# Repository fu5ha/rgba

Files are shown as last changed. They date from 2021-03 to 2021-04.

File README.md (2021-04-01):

# `rgba` - reasonably good bluetooth audio

The `rgba` is a tiny (41x20mm PCB), extremely high fidelity Bluetooth audio receiver meant to attach inline to the cord of
a pair of IEMs. It aims to provide as high quality audio as possible while retaining reasonable battery life and
its small form factor. It is designed to pair well with high sensitivity, low impedance IEMs. For use with
lower sensitivity, harder to drive headphones (or IEMs), you'll need to adjust the values of the resistor feedback network
around the Op Amp to provide the proper output power. See [this document](https://www.ti.com/lit/ug/tiduaw1/tiduaw1.pdf),
especially sections 1 through 3, for more information. Reach out to me via GitHub issue or social media (listed on my
GitHub profile) and I'd be happy to guide you on this.

## Schematic

See [rgba.pdf](/rgba.pdf) for a PDF copy of the schematic, or open the repo's root as a project in KiCad and launch Eeschema.

## Renders

Here are a couple of renders of the latest version of the PCB.

front side
back side

## Bill of Materials

A bill of materials is available in HTML format, with links to sourcing information and
interactive PCB board view useful when performing assembly. View it here: <https://termhn.github.io/rgba/ibom.html>

Not included in the BOM is a battery. You can use any single cell LiPo (3.7V) LiPo battery up to
500mAh in capacity. You'll likely need to either re-terminate the batteries with the proper connector
(2-pin JST-ACH [plug housing](https://www.digikey.com/en/products/detail/jst-sales-america-inc/ACHR-02V-S/1647783c)
and [crimp leads](https://www.digikey.com/en/products/detail/jst-sales-america-inc/ASACHSACH28W51/6009445)
can be found on DigiKey) or lop off the included connector and solder the leads directly to the board.

## PCB Sourcing

I recommend ordering PCBs through OSH Park because their 4 layer process has the needed precision at a reasonable price
(JLCPCB for example will cost you a lot more to get the needed 0.2/0.4 diameter vias), is good quality, and are a cool
organization to support. Plus their PCBs are a super purdy purple :d

You can order some of the rev 1.1 PCBs directly using this link: -link will be inserted here when it has been tested working-

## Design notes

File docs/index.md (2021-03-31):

# `rgba` - reasonably good bluetooth audio

The `rgba` is a tiny (41x20mm PCB), extremely high fidelity Bluetooth audio receiver meant to attach inline to the cord of
a pair of IEMs. It aims to provide as high quality audio as possible while retaining reasonable battery life and
its small form factor. For more information, see the [project README](https://github.com/termhn/rgba).

## Interactive Bill of Materials

[View the interactive BOM](ibom.html)

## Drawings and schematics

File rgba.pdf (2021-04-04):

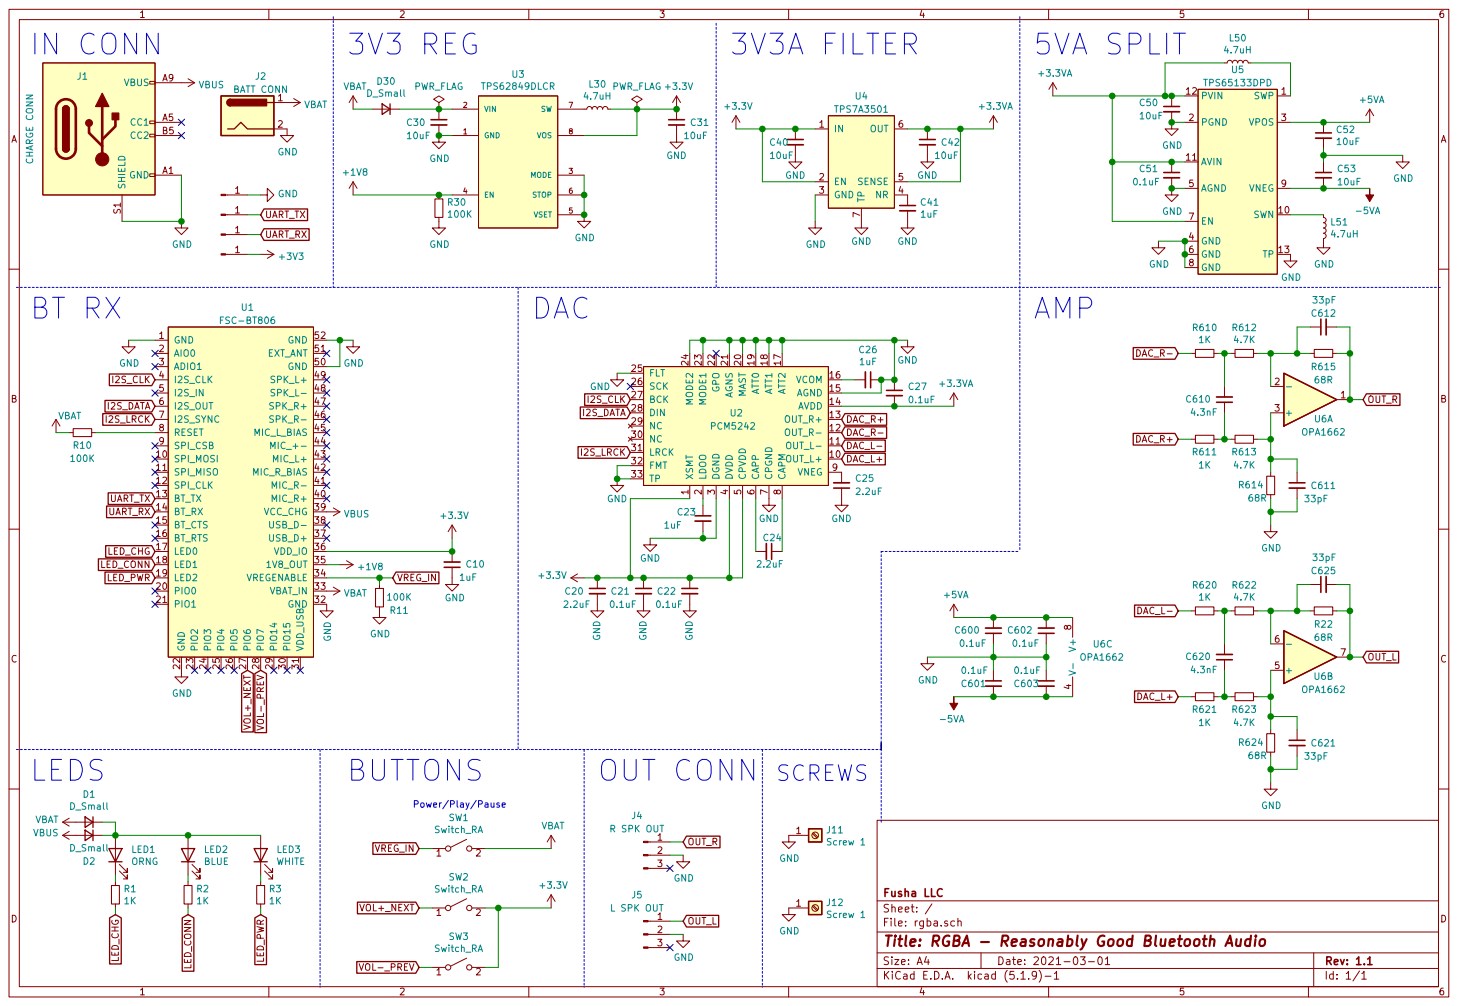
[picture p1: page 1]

2 MAST 20 AGNS 21 GPO 22 MODE1 23 MODE2 24 FLT 25 SCK 26 BCK 27 DIN 28 NC 29 DGND

1 OUT_L+ 10 OUT_L- 11 OUT_R- 12 OUT_R+ 13 AVDD 14 AGND 15 VCOM 16 ATT2 17 ATT1 18 ATT0 19 LDOO

File: rgba.sch Sheet: / Fusha LLC

Id: 1/1 Title: RGBA - Reasonably Good Bluetooth Audio

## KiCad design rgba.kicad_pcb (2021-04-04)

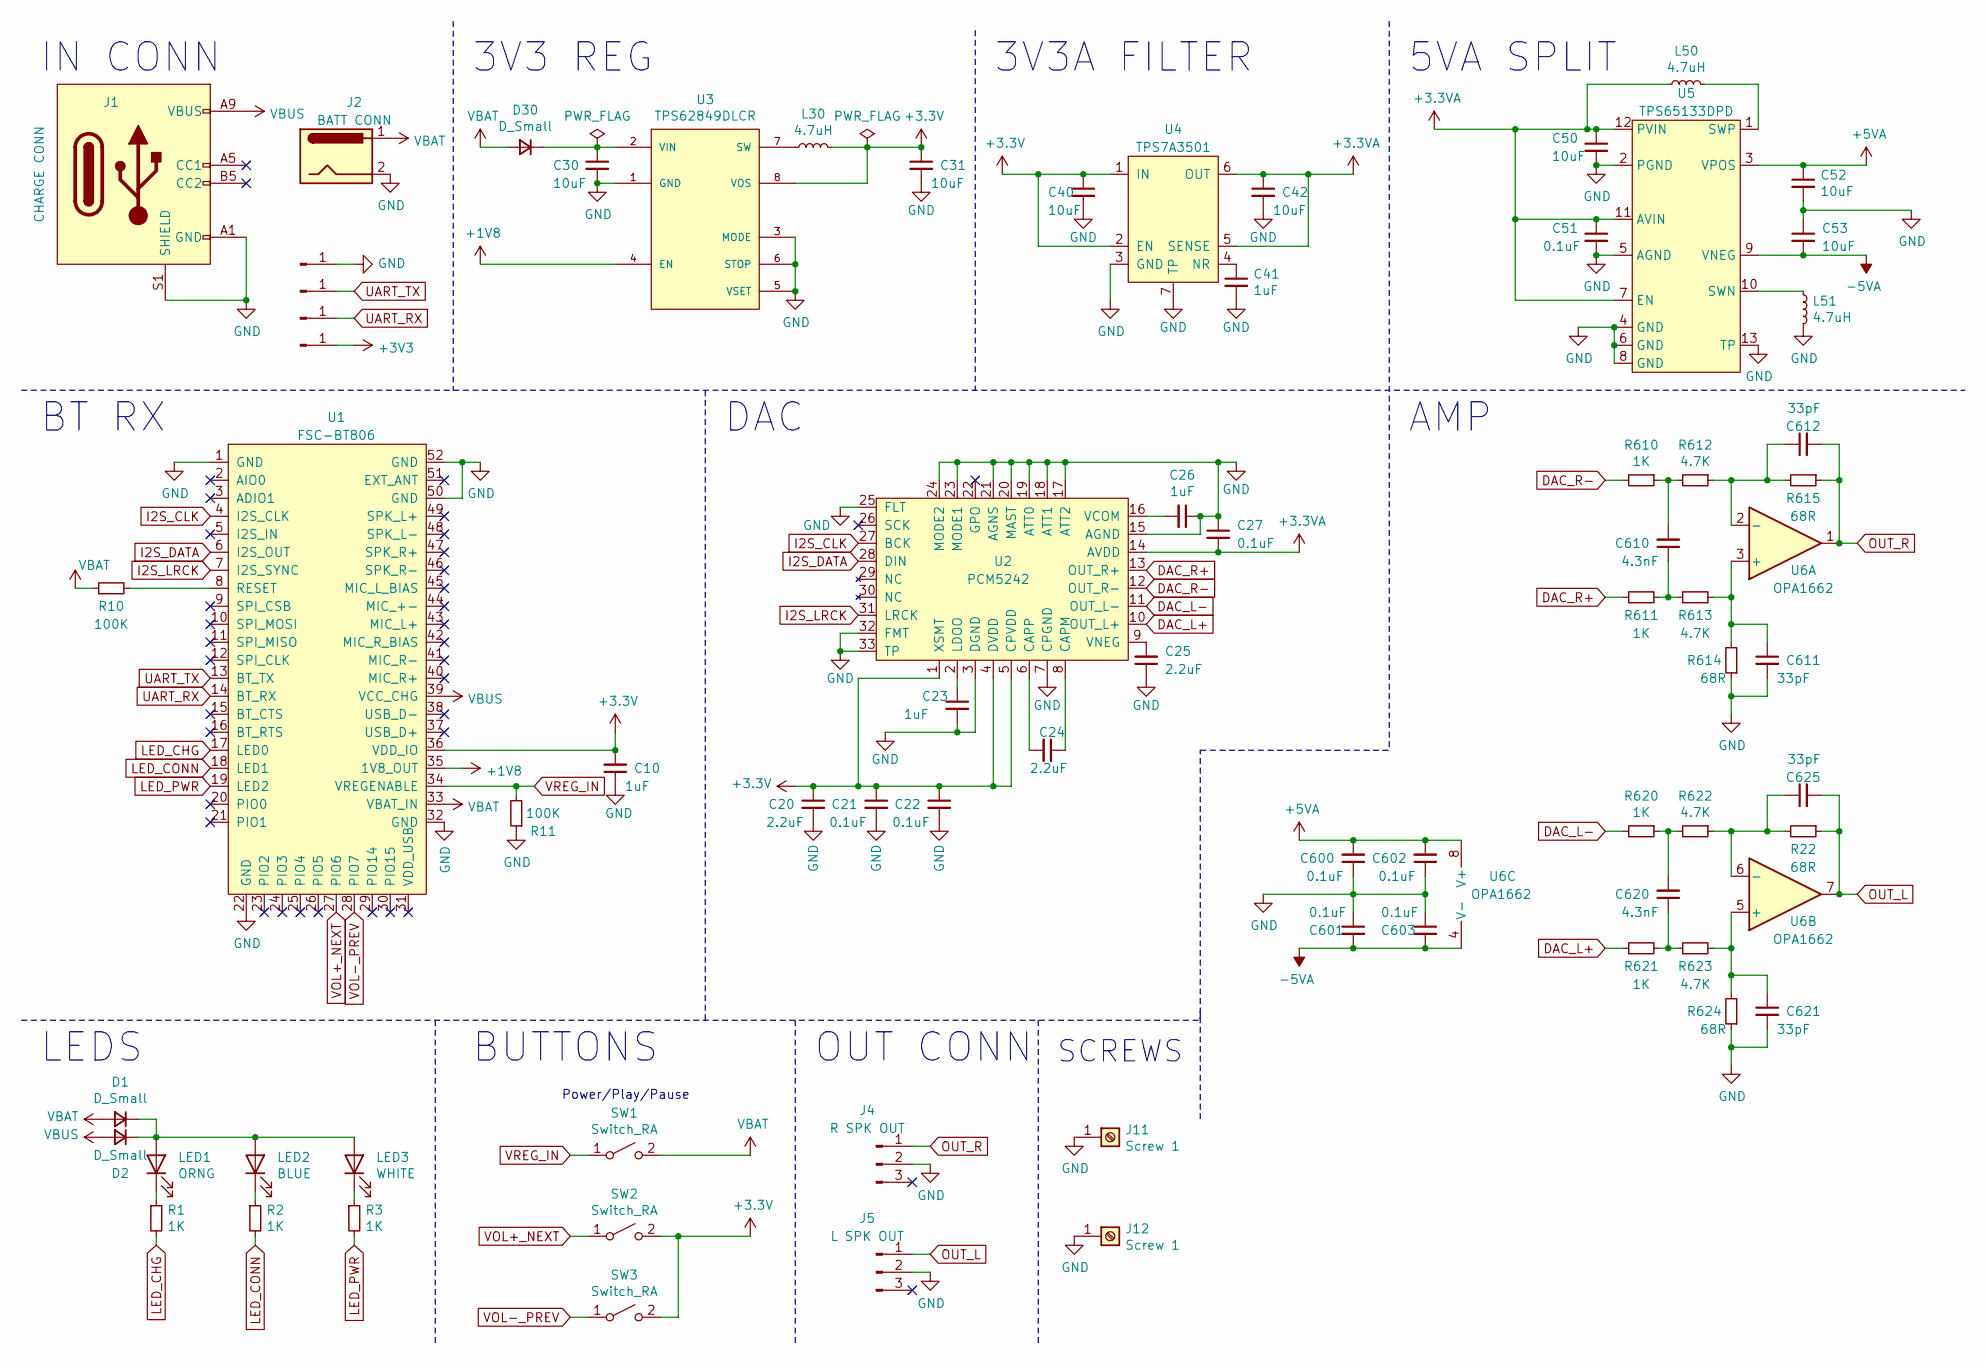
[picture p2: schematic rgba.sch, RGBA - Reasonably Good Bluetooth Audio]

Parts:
C10, C23, C26, C41: 1uF; C_0402_1005Metric_Pad0.74x0.62mm_HandSolder
C20, C24, C25: 2.2uF; C_0805_2012Metric_Pad1.18x1.45mm_HandSolder
C21, C22, C27, C51, C600, C601, C602, C603: 0.1uF; C_0402_1005Metric_Pad0.74x0.62mm_HandSolder
C30, C31, C40, C42, C50, C52, C53: 10uF; C_0402_1005Metric_Pad0.74x0.62mm_HandSolder
C610, C620: 4.3nF; C_0603_1608Metric_Pad1.08x0.95mm_HandSolder
C611, C612, C621, C625: 33pF; C_0603_1608Metric_Pad1.08x0.95mm_HandSolder
D1, D2, D30: D_Small; D_0603_1608Metric_Pad1.05x0.95mm_HandSolder
J1: CHARGE CONN; USB_C_Receptacle_UJC-HP-3-SMT-TR
J2: BATT CONN; JST_ACH_BM02B-ACHSS-GAN-ETF_1x02-1MP_P1.20mm_Vertical
J3: UART_GND; TestPoint_THTPad_D1.5mm_Drill0.7mm
J4: R SPK OUT; SolderWire_AudioOut_1x03_P2.0mm
J5: L SPK OUT; SolderWire_AudioOut_1x03_P2.0mm
J6: UART_TX; TestPoint_THTPad_D1.5mm_Drill0.7mm
J7: UART_VBUS; TestPoint_THTPad_D1.5mm_Drill0.7mm
J8: UART_RX; TestPoint_THTPad_D1.5mm_Drill0.7mm
J11, J12: Screw 1; MountingHole_1.2mm_M1_Pad
L30, L50, L51: 4.7uH; L_1008_2520Metric_Pad1.43x2.20mm_HandSolder
LED1: ORNG; LED_0603_1608Metric_Castellated
LED2: BLUE; LED_0603_1608Metric_Castellated
LED3: WHITE; LED_0603_1608Metric_Castellated
R1, R2, R3, R610, R611, R620, R621: 1K; R_0603_1608Metric_Pad0.98x0.95mm_HandSolder
R10, R11: 100K; R_0402_1005Metric_Pad0.72x0.64mm_HandSolder
R22, R614, R615, R624: 68R; R_0402_1005Metric_Pad0.72x0.64mm_HandSolder
R612, R613, R622, R623: 4.7K; R_0402_1005Metric_Pad0.72x0.64mm_HandSolder
SW1, SW2, SW3: Switch_RA; TL4110AF160Q
U1: FSC-BT806
U2: PCM5242; QFN-32-1EP_5x5mm_P0.5mm_EP3.45x3.45mm
U3: TPS62849DLCR; VSON-8_1.5x2mm_P0.5mm
U4: TPS7A3501; WSON-6-1EP_2x2mm_P0.65mm_EP1x1.6mm_ThermalVias
U5: TPS65133DPD; WSON-12-1EP_3x3mm_P0.45mm_EP1.2x2mm
U6: OPA1662; VSSOP-8_3.0x3.0mm_P0.65mm

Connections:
+1V8: U1.35 (1V8_OUT), U3.4 (EN)
+3.3VA: C27.2, C42.1, C50.1, C51.1, L50.1, U2.14 (AVDD), U4.5 (SENSE), U4.6 (OUT), U5.7 (EN), U5.11 (AVIN), U5.12 (PVIN)
+5VA: C52.1, C600.2, C602.2, U5.3 (VPOS), U6.8 (V+)
-5VA: C53.2, C601.2, C603.2, U5.9 (VNEG), U6.4 (V-)
DAC_L+: R621.1, U2.10 (OUT_L+)
DAC_L-: R620.2, U2.11 (OUT_L-)
DAC_R+: R611.1, U2.13 (OUT_R+)
DAC_R-: R610.2, U2.12 (OUT_R-)
GND: C10.1, C20.2, C21.2, C22.2, C23.2, C25.1, C26.1, C27.1, C30.2, C31.2, C40.2, C41.2, C42.2, C50.2, C51.2, C52.2, C53.1, C600.1, C601.1, C602.1, C603.1, C611.2, C621.2, J1.A1 (GND), J1.B1 (GND), J1.S1 (SHIELD), J2.2, J3.1, J4.2, J5.2, J11.1, J12.1, L51.2, R11.1, R614.1, R624.1, U1.1 (GND), U1.22 (GND), U1.32 (GND), U1.50 (GND), U1.52 (GND), U2.3 (DGND), U2.7 (CPGND), U2.15 (AGND), U2.17 (ATT2), U2.18 (ATT1), U2.19 (ATT0), U2.20 (MAST), U2.21 (AGNS), U2.23 (MODE1), U2.24 (MODE2), U2.25 (FLT), U2.32 (FMT), U2.33 (TP), U3.1 (GND), U3.3 (MODE), U3.5 (VSET), U3.6 (STOP), U4.3 (GND), U4.7 (TP), U5.2 (PGND), U5.4 (GND), U5.5 (AGND), U5.6 (GND), U5.8 (GND), U5.13 (TP)
I2S_CLK: U1.4 (I2S_CLK), U2.27 (BCK)
I2S_DATA: U1.6 (I2S_OUT), U2.28 (DIN)
I2S_LRCK: U1.7 (I2S_SYNC), U2.31 (LRCK)
LED_CHG: R1.2, U1.17 (LED0)
LED_CONN: R2.2, U1.18 (LED1)
LED_PWR: R3.2, U1.19 (LED2)
unnamed: C23.1, U2.2 (LDOO)
unnamed: C24.1, U2.8 (CAPM)
unnamed: C24.2, U2.6 (CAPP)
unnamed: C25.2, U2.9 (VNEG)
unnamed: C26.2, U2.16 (VCOM)
unnamed: C30.1, D30.1 (K), U3.2 (VIN)
unnamed: C41.1, U4.4 (NR)
unnamed: C610.1, R611.2, R613.1
unnamed: C610.2, R610.1, R612.2
unnamed: C611.1, R613.2, R614.2, U6.3 (+)
unnamed: C612.1, R612.1, R615.2, U6.2 (-)
unnamed: C620.1, R621.2, R623.1
unnamed: C620.2, R620.1, R622.2
unnamed: C621.1, R623.2, R624.2, U6.5 (+)
unnamed: C625.1, R22.2, R622.1, U6.6 (-)
unnamed: D1.1 (K), D2.1 (K), LED1.2 (A), LED2.2 (A), LED3.2 (A)
unnamed: L30.1, U3.7 (SW)
unnamed: L50.2, U5.1 (SWP)
unnamed: L51.1, U5.10 (SWN)
unnamed: LED1.1 (K), R1.1
unnamed: LED2.1 (K), R2.1
unnamed: LED3.1 (K), R3.1
unnamed: R10.2, U1.8 (RESET)
OUT_L: C625.2, J5.1, R22.1, U6.7
OUT_R: C612.2, J4.1, R615.1, U6.1
UART_RX: J8.1, U1.14 (BT_RX)
UART_TX: J6.1, U1.13 (BT_TX)
VBAT: D1.2 (A), D30.2 (A), J2.1, R10.1, SW1.2 (B), U1.33 (VBAT_IN)
VBUS: D2.2 (A), J1.A9 (VBUS), J1.B9 (VBUS), U1.39 (VCC_CHG)
VOL+_NEXT: SW2.1 (A), U1.27 (PIO6)
VOL-_PREV: SW3.1 (A), U1.28 (PIO7)
VREG_IN: R11.2, SW1.1 (A), U1.34 (VREGENABLE)

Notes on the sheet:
DAC
BT RX
IN CONN
3V3 REG
3V3A FILTER
AMP
LEDS
BUTTONS
OUT CONN
5VA SPLIT
SCREWS
Power/Play/Pause

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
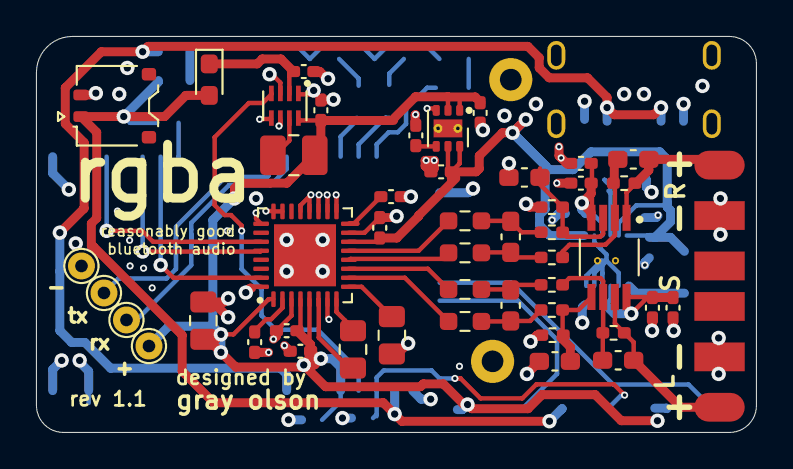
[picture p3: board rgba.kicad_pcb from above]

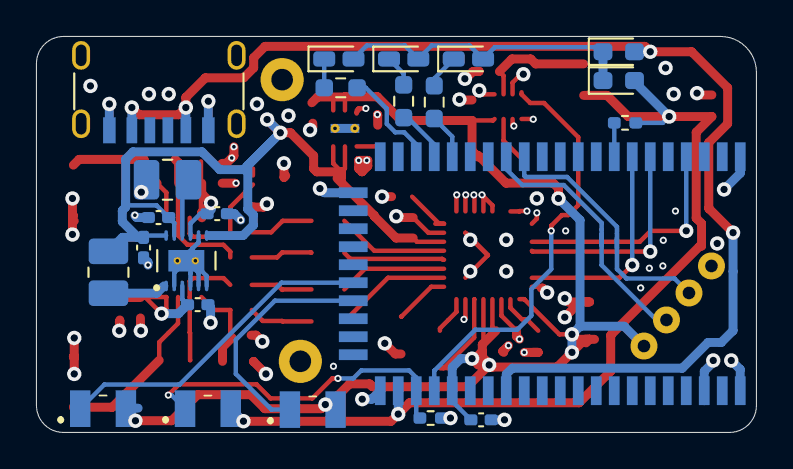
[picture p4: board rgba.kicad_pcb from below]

Board: 4 copper layers, 40.0 x 22.0 mm, 73 parts (23 on the bottom side), 48 nets.

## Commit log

2021-03-13 new 3.3v voltage regulator and updated a few footprints
    [rgba.kicad_pcb, rgba.sch, rgba_bom.xls]
2021-03-30 start working on new regulator
    [rgba-B_Cu.gbl, rgba-B_Mask.gbs, rgba-B_SilkS.gbo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]
2021-03-31 rev 1.1
    [rgba-B_Cu.gbl, rgba-B_Mask.gbs, rgba-B_SilkS.gbo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]
2021-03-31 update readme, gerbers, bom
    [rgba-B_Cu.gbl, rgba-B_Mask.gbs, rgba-B_SilkS.gbo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]
2021-04-01 modify uart header and led position
    [rgba-B_Cu.gbl, rgba-B_Mask.gbs, rgba-B_SilkS.gbo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]
2021-04-01 more size optimization
    [rgba-B_Cu.gbl, rgba-B_Mask.gbs, rgba-B_SilkS.gbo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]
2021-04-01 make UART terminals larger
    [rgba-B_Cu.gbl, rgba-B_Mask.gbs, rgba-B_SilkS.gbo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]
2021-04-04 connect programming header power to 3v3 instead of vbus
    [rgba-B_Cu.gbl, rgba-B_Mask.gbs, rgba-B_SilkS.gbo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]
2021-04-04 remove TPS62849 enable pin pulldown resistor because it has an internal pulldown resistor
    [rgba-B_Cu.gbl, rgba-B_Mask.gbs, rgba-B_SilkS.gbo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]
